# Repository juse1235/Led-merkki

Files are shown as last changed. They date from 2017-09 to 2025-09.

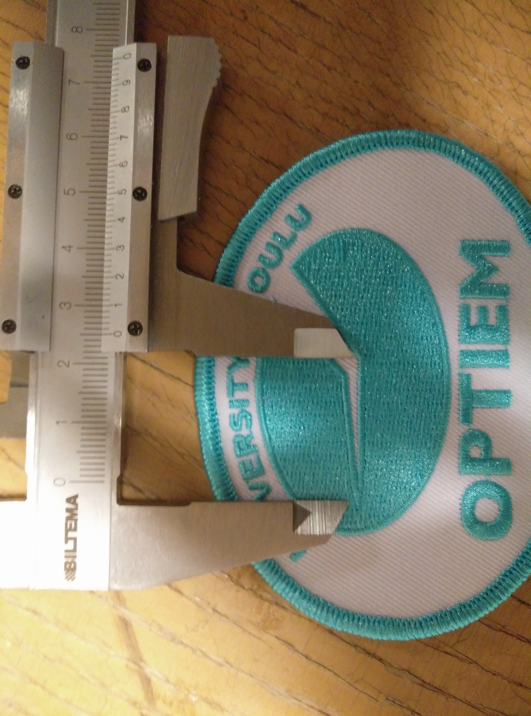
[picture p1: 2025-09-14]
kicad/optiem/kuvat/IMG_20201127_140025.jpg

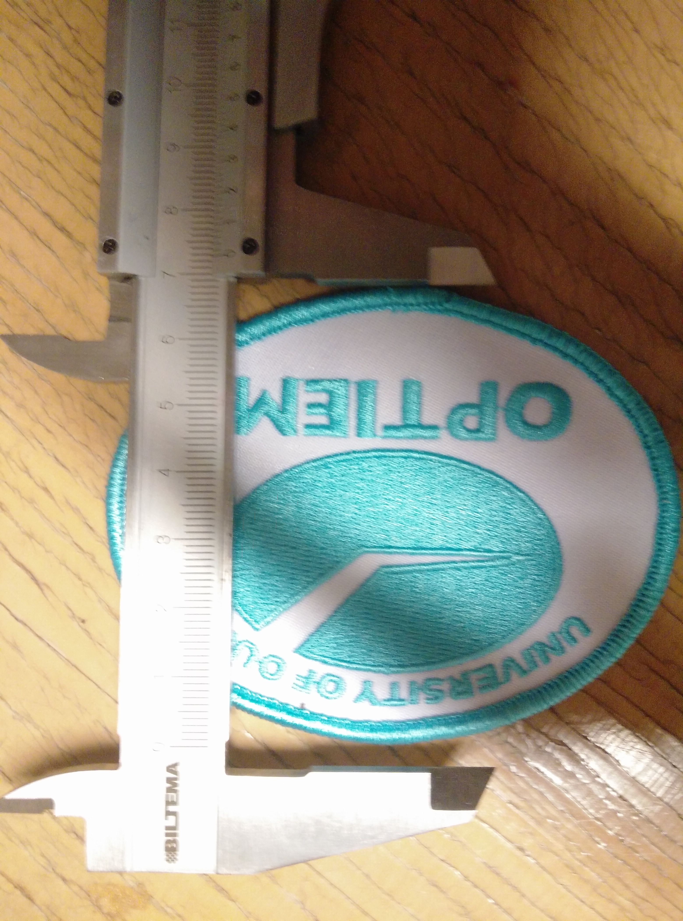
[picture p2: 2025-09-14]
kicad/optiem/kuvat/IMG_20201127_140003.jpg

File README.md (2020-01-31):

# Salama
Sikin led salamaan ja Otitin led merkkiin koodi, piirilevy ja ohjeet

## Piirilevyt
### Mistä salama koostuu ja miten se toimii
Salaman mikrokontrolleri (mcu) ohjaa ledejä sytyttäen niitä yksi kerrallaan hyvin lyhyeksi aikaa.
Ledejä on 32 ja niille on 110 ohm etuvastukset.
Salamassa on myös 5v regulaattori joka pienentää 9v paristosta saatavan jännitteen viiteen volttiin.
Regulaattori vaatii toimiakseen kondensaattorit molemmille puolilleen.
Levyyn on myös suunniteltu kytkin, jolla voisi vaikka sammuttaa laitteen tai toimittaa muuta toiminnallisuutta, mutta näitä ei ole koodissa toteutettu vielä.
Kuusipinninen liitin on ohjelmointia varten ja sitä kautta ohjelma siirretääm mikrokontrollerille.

skema Skema on jotakuinkin tällainen

### Osaluettelo
  * 1 kpl  ATtiny861a SOIC
  * 32 kpl sininen 3 mm diffusoitu led
  * 4 kpl  110 Ohm 1206 smd-vastus
  * 2 kpl  10 µF tantaalikondensaattori smd (paketti?)
  * 1 kpl  Texas Instruments LP2981AIM5-5.0/NOPB Regulaattori sot23-5
  * 1 kpl  palautuva kytkin (tyyppi?)
  * 1 kpl  9v-paristolle paristoliitin
  * 1 kpl  kuusi pinniä pitkän piikkiriman
  
  lisäksi tarvitset:
  * kaksinapaista johtoa paristoliittimelle
  * kuumaliimaa
  * haalarimerkin :-)
  
### Piirikaavio

1. Läpiviennit
  Kaksipuoleisessa levyssä läpiviennit kuljettavat sähkön levyn puolelta toiselle.

  Mikäli olet saanut levyn yliopiston piirilevypajalta, siinä on luultavasti läpiviennit ja voit ohittaa tämän vaiheen.
  Jos piirilevy on syövytetty elektroniikkakerhon piirilevypajalla siinä ei ole läpivientejä ja ne täytyy juottaa itse.
  Juota siis johdon pätkä kuvassa oleviin reikiin molemmilta puolilta ja katkaise lopuksi mahdollisimman matalaksi.

  Levyn takapuoli. Tältä puolelta näkee mihin juotetaan läpiviennit.

  back copper

2. Vastukset
  Levylle tulee neljä kappaletta 110 ohm vastuksia. Vastukset on merkattu kuviin tunnisteilla R1,R2,R3,R4.

  Pintaliitosvastus on helpoin juottaa siten, että juottaa vähän tinaa ensin piirilevyn toiselle pädille ja sitten vastus    siirretään oikealle paikalle, pidetään paikallaan painamalla jollain lämpöä kestävällä työkalulla ja painetaan kolvilla kunnes tina sulaa. Sitten voit juottaa toisen pädin normaalisti.
  
  Piirilevyn komponenttipuoli

  pcb
  front copper
  silkki
  
  ##### Otit
  
   pcb_otit
   silkki_otit
  
  TODO: tähän vois panna kuvan kasatusta levystä
  
3. Regulaattori
   Regulaattori kannattaa juottaa ensin, koska se on ahtaassa kolossa. Regulaattorin juottamisessa täytyy myös olla huolellinen, ettei synny oikosulkuja.
   
4. Mikrokontrolleri
Mikrokontrollerissa polariteetti on merkitty lovella kuvassa ja lovella tai pisteellä itse komponentissa.

5. Kondensaattorit
  Tantaalikondensaattorissa polariteetti on merkitty viivalla joka tarkoitta positiivista puolta. Piirilevylle on piirretty paikat neljälle konkalle, kytke kuitenkin vain kaksi C3 ja C4.
  
6. Ohjelmointiliitin
  Juota pätkä piikkirimaa vaakatasoon. Liitin on kuvassa merkitty P1 ja siihen tulee kuusi pinniä.
  TODO: Kuva aiheesta selventäisi..

7. Kytkin
  Tällä hetkellä kytkimelle ei ole ohjelmoitu toiminnallisuutta, mutta sen juottaminen on niin pieni vaiva että se kannattanee kuitenkin tehdä. Kytkin siis asennetaan ylösalaisin niin että kytkimen hattu on levyn tasolla. Tarkoitus on siis että haalarimerkin läpi sitä olisi helppo painaa, mutta kuitenkin sitä ei tulisi vahingossa painettua.
  TODO: Lissää kuvia..
  
8. Ledit
  Ledien juottamisessa on suurin työmaa merkin valmistuksessa. Työtä aiheuttaa lähinnä ledin painaminen merkistä läpi.
  Ensin pitää huomioida polariteetti. Jos olet nähnyt paljon vaivaa että olet laittanut ledit miten sattuu niin voipi harmittaa..
  
  Elektroniikkakerholla on hankittu yleensä mahdollisimman edullisia ledejä joten voisi olla hyvä ennen juottamista testata ledit virtalähteellä. 
  
  Ledien jalat täytyy teroittaa leikkaamalla ne sivuleikkurilla mahdollisimman viistosti, niin että niistä tulee mahdollisimman terävät merkin läpi painamista varten. Leikkaa myös jalat reilusti eri mittaisiksi. Ne on helpompi painaa lapi yksi kerrallaan pihdeillä.
  
  Salaman ylä ja alapäässä on kaksi lediä piirretty niin lähellä toisiaan, että ledejä olisi hyvä vähän viilata jotta ne saa osoittamaan suoraan. (Aikaisemmassa leiskassa ledeillä oli tarpeeksi etäisyyttä mutta ne eivät pysyneet linjassa niin piirsin näin :-) )
  
  TODO: KUVA!!!
  
  Haalarimerkki kannattaa tässä vaiheessa kiinnittää ylimmän ja alimman ledin reistä johtimella kiinni oikealle kohdalle, helpottaa kasaamista. Itse olen kokenut käteväksi työmenetelmäksi että painan johtimen piirilevyn puolelta läpi ja sitten lämmitän sitä merkin puolelta niin että merkkiin sulaa/palaa pieni piste, josta sitten tietää mistä kohdasta ledin jalka kannattaa painaa läpi.

8. Virtajohto
  Virtajohto kannattaa liittää viimeisenä, koska se hankaloittaa levyn käsittelyä. Mitoita virtajohdon pituus niin, että se riittää taskuun missä aiot paristoa säilyttää paikasta johon merkin aiot ommella.
Johdon toiseen päähän juotetaan 9v-paristolle paristoliitin. Elekerholla on ollut huonoja paristoliittimiä joiden johdot ovat katkeilleet herkästi, joten liitin kannattaa ehkä purkaa, poistaa alkuperäiset johdot ja juottaa uusi johto tilalle. Paristoliitin suojataan kuumaliimalla.

  Kiinnitä huomiota polariteettiin. Salamaan ei ole suunniteltu suojaa väärinpäinkytkemisen varalta ja regulaattori palaa välittömästi kun näin tapahtuu. (Suojadiodin lisääminen olisi aika triviaalia) 
  TODO: Tähänki vois panna kuvan!

9. Ohjelmointi
  Ohjelmointiin on ohjeet jäljempänä.
  
10. Lopuksi kun on varmistettu että levy toimii oikein se kannattaa suojata kuumaliimalla niin että ledien terävät jalat peittyvät. Kytkin ja virtajohto kannattaa myös varmistaa hyvin. Merkkiä on vaikea korjata, kun se on kiinni haalareissa.

Todo: Syövytystä varten maskit. Sik maski saattaa löytyä vielä jostain. Otitille ei ole tehty vaan levyt jyrsittiin.

## Ohjelma

Ohjelma siirtyy levylle kätevästi käyttäen arduinoa ohjelmointilaitteena.

```
Salaman ohjelmointiliittimen pinnit keskeltä reunalle:

Nro:  Nimi:   Arduinon pinni (nano):

6:    Reset   10
5:    GND     GND
4:    VCC     VCC
3:    SCK     13
2:    MISO    12
1:    MOSI    11

Muista vetää arduinon Reset ylös. Ardu nollautuu kun sarjaliikenne alotetaan....
```

Src hakemistossa on lediportit_oikein.h ja lediportit_väärin.h tiedostot joista jompikumpi kopioidaan lediportit.h tiedoston päälle mikäli ledit on juotettu vastoin ohjetta. (TODO: nimet ovat ehkä väärin)

Koodin kääntämiseen ja ohjelman levylle siirtämiseen komennot ovat:

##### Linux ja Mac

```
// kääntäminen
avr-gcc -mmcu=attiny861 vilkutus.c salama.c -I./ -Os -DF_CPU=8000000UL  

// Fläsäys käyttäen arduino-isp:tä
avrdude -c avrisp -p t861 -B3 -P /dev/ttyUSB0 -b 19200 -U flash:w:a.out

// Fuse asetukset käyttäen arduino-isp:tä
avrdude -c avrisp -p t861 -B3 -P /dev/ttyUSB0 -b 19200 -U lfuse:w:0xe2:m -U hfuse:w:0xdf:m
```
##### Windows

```
// kääntäminen
avr-gcc -mmcu=attiny861 vilkutus.c salama.c -I./ -Os -DF_CPU=8000000UL

// Fläsäys käyttäen arduino-isp:tä
avrdude -C "C:\Program Files (x86)\Arduino\hardware\tools\avr\etc\avrdude.conf" -c avrisp -p t861 -B3 -P COM7 -b 19200 -U flash:w:a.out

// Fuse asetukset käyttäen arduino-isp:tä
avrdude -C "C:\Program Files (x86)\Arduino\hardware\tools\avr\etc\avrdude.conf" -c avrisp -p t861 -B3 -P COM7 -b 19200 -U lfuse:w:0xe2:m -U hfuse:w:0xdf:m
```
Windowsilla avrdude pitää olla ympäristömuuttujissa. Toinen vaihtoehto on ajaa komento "\Arduino\hardware\tools\avr\bin"-kansiossa.

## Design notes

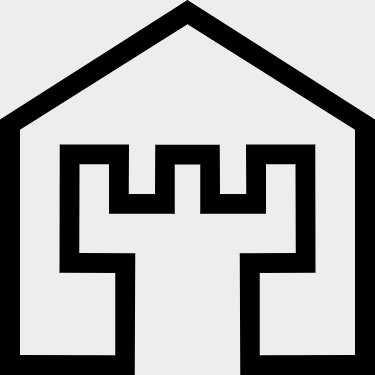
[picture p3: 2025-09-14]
kicad/ark/ark.bmp

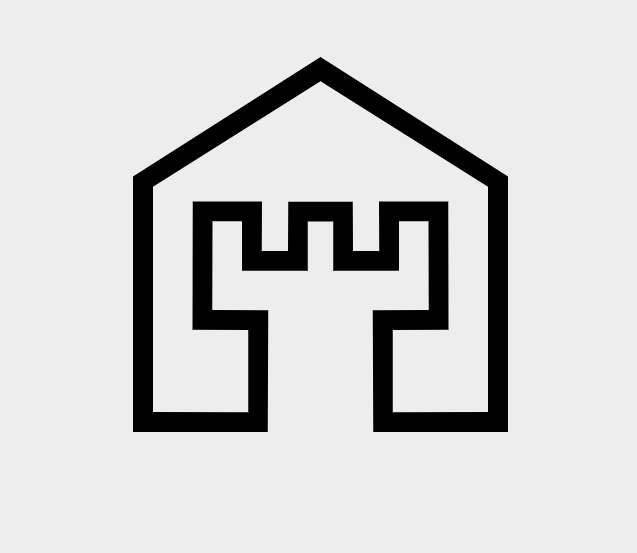
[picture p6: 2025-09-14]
kicad/ark/ark.png

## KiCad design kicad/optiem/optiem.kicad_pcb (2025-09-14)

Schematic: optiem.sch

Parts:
C1: CP1; CP_EIA-6032-15_Kemet-U_Pad2.25x2.35mm_HandSolder
D1, D2, D3, D4, D5, D6, D7, D8, D9, D10, D11, D12, D13, D14, D15, D16, D17, D18, D19, D20, D21, D22, D23, D24, D25, D26, D27, D28, D29, D30, D31, D32: LED; LED_D3.0mm
F1: Polyfuse; R_0805_2012Metric_Pad1.20x1.40mm_HandSolder
IC1: ATTINY861-S; SO-20_12.8x7.5mm_P1.27mm_extended
P1: CONN_6; Ohjelmointiliitin
P2, P3: CONN_2; PinSocket_1x02_P2.54mm_Horizontal
R1, R2, R3, R4: 110; R_1210_3225Metric_Pad1.30x2.65mm_HandSolder

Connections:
GND: C1.2, IC1.6, IC1.16, P1.5, P2.1, P3.1
unnamed: D1.1 (K), D9.1 (K), D17.1 (K), D25.1 (K), IC1.14
unnamed: D1.2 (A), D2.2 (A), D3.2 (A), D4.2 (A), D5.2 (A), D6.2 (A), D7.2 (A), D8.2 (A), R1.2
unnamed: D2.1 (K), D10.1 (K), D18.1 (K), D26.1 (K), IC1.13
unnamed: D9.2 (A), D10.2 (A), D11.2 (A), D12.2 (A), D13.2 (A), D14.2 (A), D15.2 (A), D16.2 (A), R2.2
unnamed: D3.1 (K), D11.1 (K), D19.1 (K), D27.1 (K), IC1.12
unnamed: D4.1 (K), D12.1 (K), D20.1 (K), D28.1 (K), IC1.11
unnamed: D5.1 (K), D13.1 (K), D21.1 (K), D29.1 (K), IC1.4
unnamed: D6.1 (K), D14.1 (K), D22.1 (K), D30.1 (K), IC1.7
unnamed: D7.1 (K), D15.1 (K), D23.1 (K), D31.1 (K), IC1.8
unnamed: D8.1 (K), D16.1 (K), D24.1 (K), D32.1 (K), IC1.3, P1.3
unnamed: D17.2 (A), D18.2 (A), D19.2 (A), D20.2 (A), D21.2 (A), D22.2 (A), D23.2 (A), D24.2 (A), R3.2
unnamed: D25.2 (A), D26.2 (A), D27.2 (A), D28.2 (A), D29.2 (A), D30.2 (A), D31.2 (A), D32.2 (A), R4.2
unnamed: F1.2, P2.2
unnamed: IC1.1, P1.1
unnamed: IC1.2, P1.2
unnamed: IC1.10, P1.6
unnamed: IC1.17, R4.1
unnamed: IC1.18, R3.1
unnamed: IC1.19, R2.1
unnamed: IC1.20, R1.1
VCC: C1.1, F1.1, IC1.5, IC1.15, P1.4, P3.2

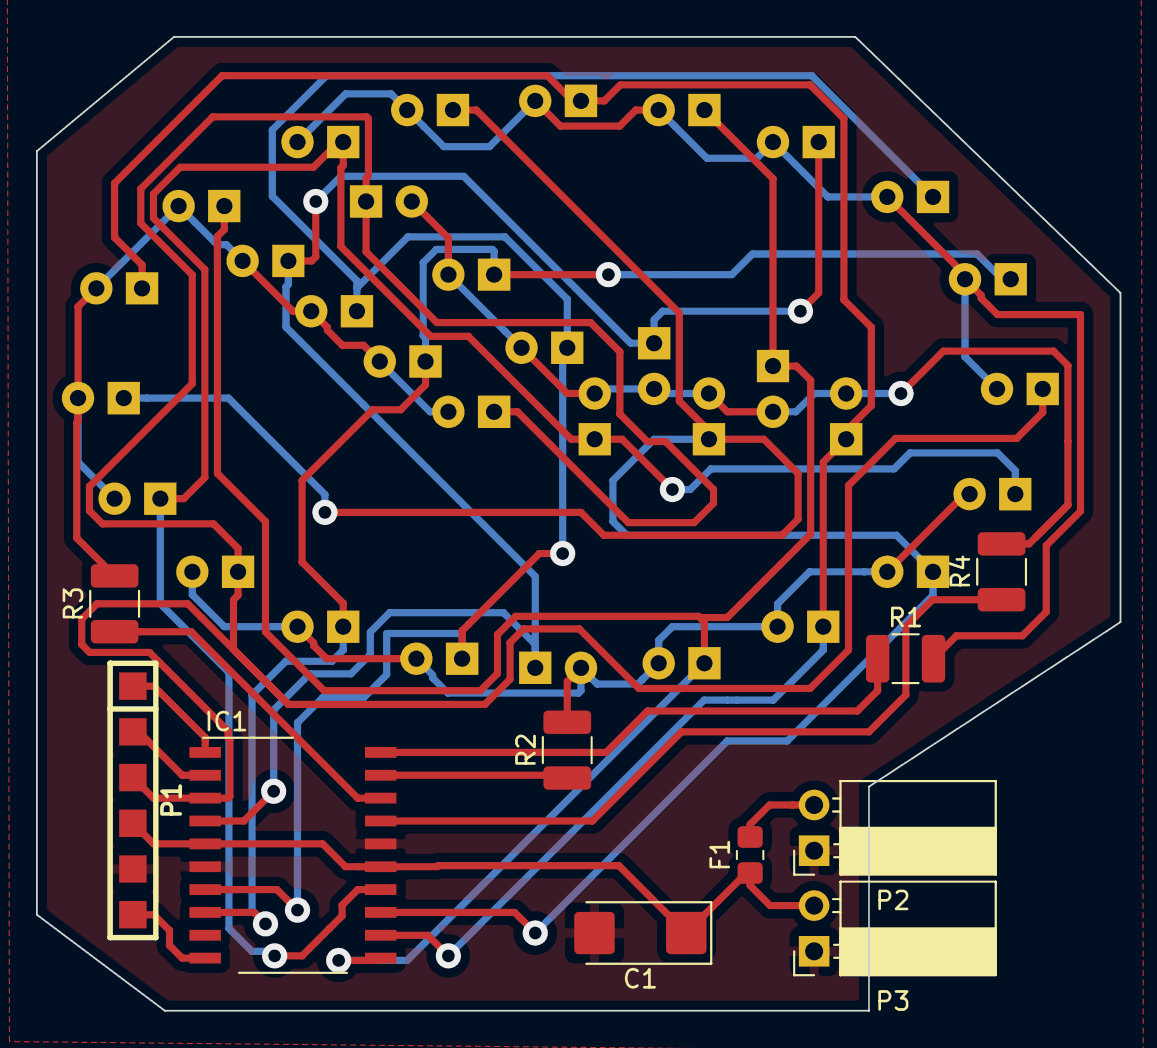
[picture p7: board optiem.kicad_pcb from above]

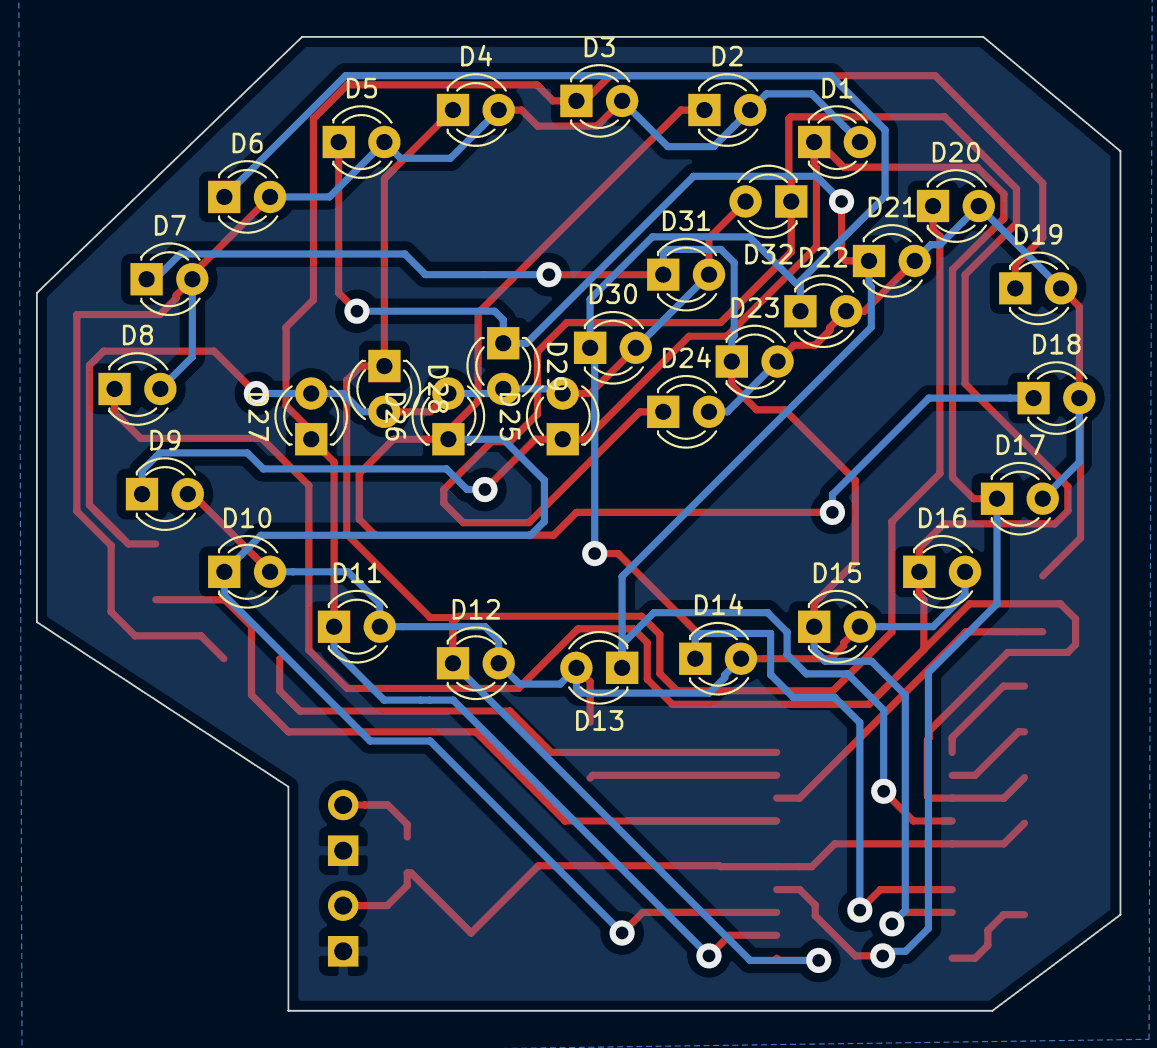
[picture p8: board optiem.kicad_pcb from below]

Board: 2 copper layers, 60.2 x 54.1 mm, 42 parts (32 on the bottom side), 22 nets.

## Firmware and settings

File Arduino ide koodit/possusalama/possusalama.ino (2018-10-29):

#define K1 0.001
#define K2 0.2
#define K3 1
#define K4 2
#define K5 4
#define K6 8
#define K7 14
#define K8 27
#define K9 50
#define K10 80
#define K11 110
#define K12 160
#define K13 200
#define K14 250
#define K15 312

///pimeä vaihe
#define P0 312
#define P1 312-K1
#define P2 312-K2
#define P3 312-K3
#define P4 312-K4
#define P5 312-K5
#define P6 312-K6
#define P7 312-K7
#define P8 312-K8
#define P9 312-K9
#define P10 312-K10
#define P11 312-K11
#define P12 312-K12
#define P13 312-K13
#define P14 312-K14
#define P15 0

uint8_t alloff_pa = 0b11110000;
uint8_t alloff_pb = 0b00111100;


//                  76543210
uint8_t pa[32] = {0b11100001,  // 0
                  0b11010001,  // 2
                  0b10110001,  // 3
                  0b01110001,  // 4
                  0b11110001,  // 5
                  0b11110001,  // 6
                  0b11110001,  // 7
                  0b11110001,  // 8
                  0b11100010,  // 9
                  0b11010010,  // 01
                  0b10110010,  // 00
                  0b01110010,  // 02
                  0b11110010,  // 03
                  0b11110010,  // 04
                  0b11110010,  // 05
                  0b11110010,  // 06
                  0b11100100,  // 07
                  0b11010100,  // 08
                  0b10110100,  // 09
                  0b01110100,  // 21
                  0b11110100,  // 20
                  0b11110100,  // 22
                  0b11110100,  // 23
                  0b11110100,  // 24
                  0b11101000,  // 25
                  0b11011000,  // 26
                  0b10111000,  // 27
                  0b01111000,  // 28
                  0b11111000,  // 29
                  0b11111000,  // 31
                  0b11111000,  // 30
                  0b11111000}; // 32

uint8_t pb[32] = {0b00111100,   // 0
                  0b00111100,
                  0b00111100,
                  0b00111100,
                  0b00110100,   // 5
                  0b00101100,
                  0b00011100,
                  0b00111000,
                  0b00111100,
                  0b00111100,   // 01
                  0b00111100,
                  0b00111100,
                  0b00110100,
                  0b00101100,
                  0b00011100,   // 05
                  0b00111000,
                  0b00111100,
                  0b00111100,
                  0b00111100,
                  0b00111100,   // 21
                  0b00110100,
                  0b00101100,
                  0b00011100,
                  0b00111000,
                  0b00111100,   // 25
                  0b00111100,
                  0b00111100,
                  0b00111100,
                  0b00110100,
                  0b00101100,   // 31
                  0b00011100,
                  0b00111000}; // 32


int8_t kirkkaus[32] = {0};


void setup (){
//       76543210
DDRB = 0b00111100;
DDRA = 0b11111111;
PORTA = 0b00001111;
PORTB = 0b00000000;
}

void loop(){
   //kaikki();
   //kirkkaustesti();
   himmennys(2,7); //(kerrat,nopeus)
   ympari(6,4);    //(kerrat,nopeus)
   /*for(int j=0;j<7;j++){
    scan(7);       //(nopeus)
   }
   for(int j=0;j<5;j++){
    fill();
   }*/
} 


void himmennys(uint16_t kerrat, uint8_t nopeus)
   {
   uint8_t i;
   int8_t v; //vrit
   uint16_t k; // kerrat
   for (k = 0; k < kerrat; k++)
      {
      for (v = 1; v <=15; v++)
         {
         for (i = 0; i <= 31; i++)
            {
            kirkkaus[i] = v;
            }
         for (i = 0; i <= nopeus; i++)
            {
            vilkutus(0);
            }
         }

      for (v = 14; v >= 1; v--)
         {
         for (i = 0; i <= 31; i++)
            {
            kirkkaus[i] = v;
            }
         for (i = 0; i <= nopeus; i++)
            {
            vilkutus(0);
            }
         }
      }
   }
void kirkkaustesti()
   {
   int i;
   for (i = 0 ; i<=15; i++)
      {
      kirkkaus[i] = i;
      }
   vilkutus(0);
   return;
   }
void kaikki()
   {
      int i;
      for (i = 0; i<=31; i++)
         {
         kirkkaus[i] = 1;
         }
      vilkutus(0);
   }

void ympari(uint16_t ctr, uint8_t nopeus)
   {
   ctr = ctr*32;
   uint8_t k = 0;
   volatile uint8_t j = 0; // missä mennään yhdessä framessa
   uint8_t t = 0; //countteri kunnes pysäytetään
   int8_t i = 0;
   uint8_t g = 0; //
//sisnhivytys
   /*for (i=0;i<16;i++)
      {
      kirkkaus[k] = i-15;
      k++;
      }
   for (i=15; i>1; i -= 3)
      {
      kirkkaus[k] = i-15;
      k++;
      }
   for (i=0; i<15; i++)
      {
      for (g = 0; g <= nopeus; g++)
         {
         vilkutus(0);
         }
      for (k=29; k>0; k--) //29 = ledit mihin yllä asetettiin negatiiviset luvut
         {
         kirkkaus[i] = kirkkaus[i]+1;
         }
      }

   k=0;
*/

//itse kuvio looppi
   while (t < ctr)
      {
      g = nopeus;
      while (g > 0) 
         {
         g--;
         k = 0;
         for (i=0;i<16;i++)
            {
            if (k+j > 31)
               kirkkaus[k+j-32] = i;
            else
               kirkkaus[k+j] = i;
            k++;
            }
         for (i=15; i>1; i -= 3)
            {
            if (k+j > 31)
               kirkkaus[k+j-32] = i;
            else 
               kirkkaus[k+j] = i;
            k++;
            }
         vilkutus(0);
         
         }
      j++;
      if (j>31)
         j = 0;
      t++;
      }
   }

void fill(){
    for(int i=0;i<32;i++){
      kirkkaus[i] = 15;
      vilkutus(0);
      delay(10);
    }
    for(int i=0;i<32;i++){
      kirkkaus[i] = 0;
      vilkutus(0);
      delay(10);
    }

}


void scan(int nopeus){
  for(int i=0;i<14;i++){
    kirkkaus[i] = 15;
    if(i<7){
      kirkkaus[32-i] = 15;
    }
    else{
      kirkkaus[26-i] = 15;
    }
    
    if(i==6){
      for(int k=20;k<26;k++){
        kirkkaus[k] = 15;
      }
    }
    if(i==8){
      for(int k=20;k<26;k++){
        kirkkaus[k] = 0;
      }
    }
    if(i==0){
      kirkkaus[13] = 0;
    }
    else{
      kirkkaus[i-1]= 0;
      if(i<8){
        kirkkaus[33-i]= 0;
      }
      else{
        kirkkaus[27-i]= 0;
      }
    }
    for(int i=0;i<nopeus;i++){
      vilkutus(0);
    }
  }
}


/*
void tauko(uint16_t ctr)
   {
   while (ctr != 0)  
      {
      asm volatile("nop"); 
      ctr--;
      }

   }

void tauko2(uint16_t ctr)
   {
   while (ctr != 0)
      {
      _delay_ms(1);
      ctr--;
      }
   }
*/
void vilkutus(int n)
{
   uint8_t led = 0;
   uint8_t *kirkptr;
   uint8_t *paptr;
   uint8_t *pbptr;
   kirkptr = &kirkkaus[0]; //kirkkaustaulukon pointteri
   paptr = &pa[0]; //PortA taulukon pointteri
   pbptr = &pb[0];
   while (led < 32)
   {
      switch (*kirkptr)
         {
         case 0:
            break;
         case 1:
            PORTA = *paptr;
            PORTB = *pbptr;
            delayMicroseconds(K1);
            //PORTA = alloff_pa;
            //PORTB = alloff_pb;

            break;
         case 2:
            PORTA = *paptr;
            PORTB = *pbptr;
            delayMicroseconds(K2);
            //PORTA = alloff_pa;
            //PORTB = alloff_pb;
            break;
         case 3:
            PORTA = *paptr;
            PORTB = *pbptr;
            delayMicroseconds(K3);
            //PORTA = alloff_pa;
            //PORTB = alloff_pb;
            break;
         case 4:
            PORTA = *paptr;
            PORTB = *pbptr;
            delayMicroseconds(K4);
            //PORTA = alloff_pa;
            //PORTB = alloff_pb;
            break;
         case 5:
            PORTA = *paptr;
            PORTB = *pbptr;
            delayMicroseconds(K5);
            //PORTA = alloff_pa;
            //PORTB = alloff_pb;
            break;
         case 6:
            PORTA = *paptr;
            PORTB = *pbptr;
            delayMicroseconds(K6);
            //PORTA = alloff_pa;
            //PORTB = alloff_pb;
            break;
         case 7:
            PORTA = *paptr;
            PORTB = *pbptr;
            delayMicroseconds(K7);
            //PORTA = alloff_pa;
            //PORTB = alloff_pb;
            break;
         case 8:
            PORTA = *paptr;
            PORTB = *pbptr;
            delayMicroseconds(K8);
            //PORTA = alloff_pa;
            //PORTB = alloff_pb;
            break;
         case 9:
            PORTA = *paptr;
            PORTB = *pbptr;
            delayMicroseconds(K9);
            //PORTA = alloff_pa;
            //PORTB = alloff_pb;
            break;
         case 10:
            PORTA = *paptr;
            PORTB = *pbptr;
            delayMicroseconds(K10);
            //PORTA = alloff_pa;
            //PORTB = alloff_pb;
            break;
         case 11:
            PORTA = *paptr;
            PORTB = *pbptr;
            delayMicroseconds(K11);
            //PORTA = alloff_pa;
            //PORTB = alloff_pb;
            break;
         case 12:
            PORTA = *paptr;
            PORTB = *pbptr;
            delayMicroseconds(K12);
            //PORTA = alloff_pa;
            //PORTB = alloff_pb;
            break;
         case 13:
            PORTA = *paptr;
            PORTB = *pbptr;
            delayMicroseconds(K13);
            //PORTA = alloff_pa;
            //PORTB = alloff_pb;
            break;
         case 14:
            PORTA = *paptr;
            PORTB = *pbptr;
            delayMicroseconds(K14);
            //PORTA = alloff_pa;
            //PORTB = alloff_pb;
            break;
         case 15:
            PORTA = *paptr;
            PORTB = *pbptr;
            delayMicroseconds(K15);
            //PORTA = alloff_pa;
            //PORTB = alloff_pb;
            break;
         default: // negatiiviset ajatellaan nolliksi
            break;
         }

      kirkptr++;
      paptr++;
      pbptr++;
      led++;
   }

   ///sammuttelu ja venailu

  if(n==0){
    PORTA = alloff_pa;
    PORTB = alloff_pb; 
  }
   //PORTA = pa[16];
   //PORTB = pb[16];
   led = 0;
   kirkptr = &kirkkaus[0]; //kirkkaustaulukon pointteri
   while (led < 32)
      {
      switch (*kirkptr)
         {
         case 0:
            delayMicroseconds(P0);
            break;
         case 1:
            delayMicroseconds(P1);
            break;
         case 2:
            delayMicroseconds(P2);
            break;
         case 3:
            delayMicroseconds(P3);
            break;
         case 4:
            delayMicroseconds(P4);
            break;
         case 5:
            delayMicroseconds(P5);
            break;
         case 6:
            delayMicroseconds(P6);
            break;
         case 7:
            delayMicroseconds(P7);
            break;
         case 8:
            delayMicroseconds(P8);
            break;
         case 9:
            delayMicroseconds(P9);
            break;
         case 10:
            delayMicroseconds(P10);
            break;
         case 11:
            delayMicroseconds(P11);
            break;
         case 12:
            delayMicroseconds(P12);
            break;
         case 13:
            delayMicroseconds(P13);
            break;
         case 14:
            delayMicroseconds(P14);
            break;
         case 15:
            delayMicroseconds(P15);
            break;
         default:
            delayMicroseconds(P15);
            break;
         }
      kirkptr++;
      led++;
      }
   }

void allOff(){
   PORTA = alloff_pa;
   PORTB = alloff_pb;
}

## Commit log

2017-09-09 Siirsin kamat tänne
    [otit.dsn, otit.kicad_pcb, otit.sch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]
2025-09-14 Added Kicad project files
    [ark.kicad_pcb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]
